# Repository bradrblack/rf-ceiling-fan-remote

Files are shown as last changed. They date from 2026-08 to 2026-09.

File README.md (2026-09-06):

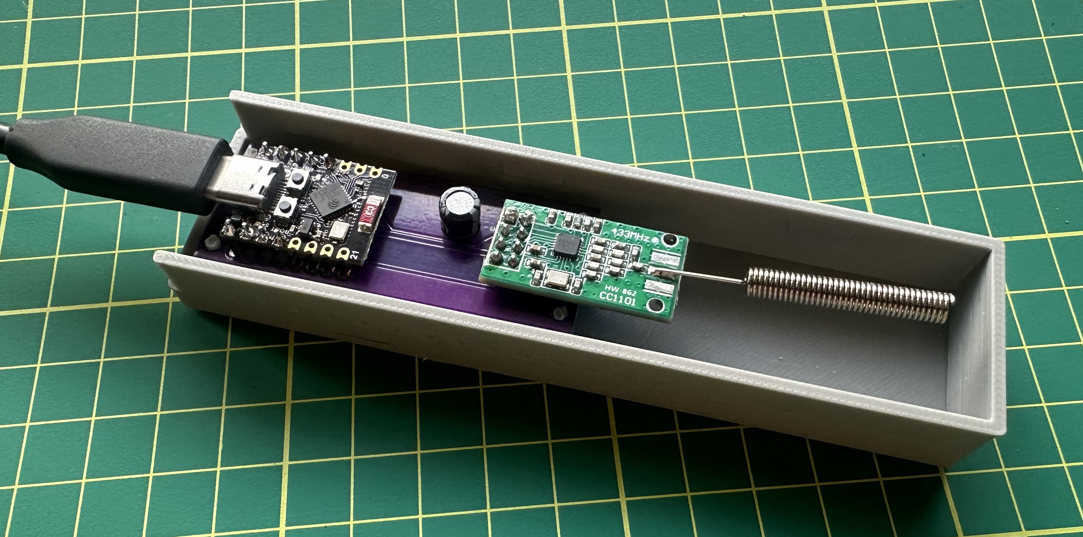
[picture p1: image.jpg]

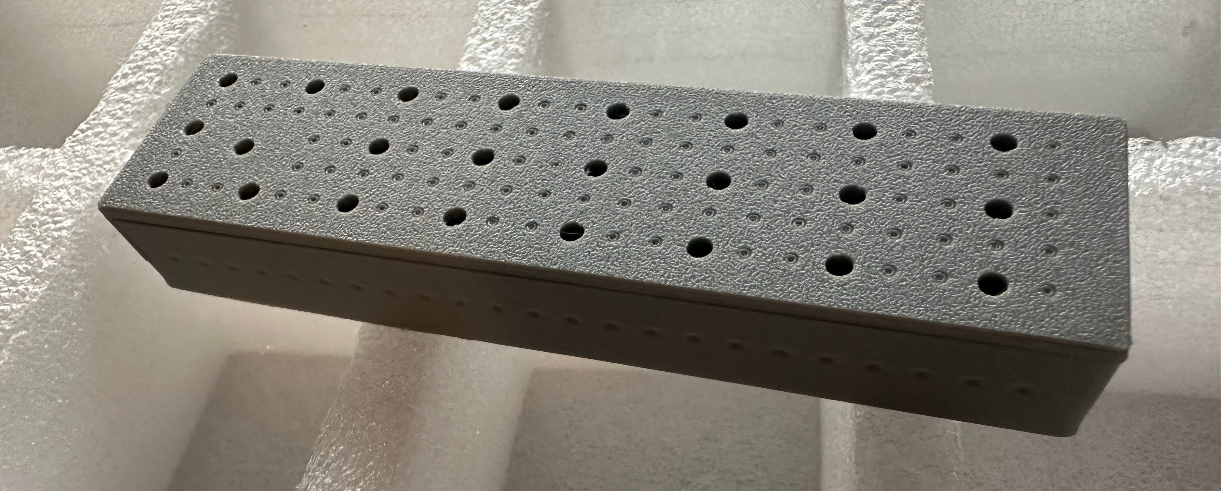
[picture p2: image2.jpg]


# rf-ceiling-fan-remote

Voice control for a combo ceiling fan + light, driven by directly cloning the RF remote's signal instead of physically pressing its buttons.

## Background

The original version of this project used a relay module wired across the buttons on the fan's remote control, triggered by an ESP32 listening on an Adafruit IO feed (fed via IFTTT/Google Assistant or iOS Shortcuts). It worked, but relays clicking against physical remote buttons is mechanically unreliable, and Google later removed the IFTTT conversational-actions feature that made flexible voice phrases possible.

This version replaces the relay entirely: a CC1101 RF transceiver connected directly to the ESP32 sniffs the remote's actual RF codes once, and then re-transmits them on command. Voice control goes through [SinricPro](https://sinric.pro), which exposes the fan and light as native devices in Google Home/Assistant (no relay, no fixed IFTTT phrases, natural voice commands like "set the fan to medium").

## Hardware

- ESP32-C3 Super Mini
- CC1101 RF transceiver module (433MHz-marketed hardware; this fan's remote actually operates at 304.25MHz, which the CC1101's synthesizer can still tune to directly)
- The fan's original remote control (used once, to sniff its codes)

## Wiring

| CC1101 pin | ESP32-C3 Super Mini pin |
|---|---|
| VCC | 3V3 (**3.3V only** — do not connect to 5V) |
| GND | GND |
| SCK | GPIO4 |
| MOSI | GPIO6 |
| MISO | GPIO5 |
| CS / SS | GPIO7 |
| GDO0 | GPIO3 |

A 100µF capacitor across the CC1101's VCC/GND pins (as close to the module as possible) was needed to get reliable SPI communication once the module started drawing the higher current TX requires — worth including if you build this yourself.

## Project structure

This is a multi-sketch PlatformIO project — each `.ino`/`.cpp` lives in its own subdirectory under `src/`, with a matching `[env]` in `platformio.ini` that filters the build to just that sketch:

| Environment | Source | Purpose |
|---|---|---|
| `c3_mini` (default) | `src/sniff.ino` | Listens on the CC1101 and prints the decimal code, bit length, protocol number, and pulse length for every button pressed on the physical remote. Run this first to capture your own remote's codes. |
| `c3_mini_tx` | `src/tx_test/` | Standalone transmit test — sends a single code on a timer, used for bench-testing range and signal timing independent of SinricPro/WiFi. |
| `c3_mini_fan` | `src/fan_control/` | The production firmware: connects to WiFi and SinricPro, and re-transmits the correct RF code when a fan or light command comes in. Also supports an optional second fan, independently TR313A or SST12 — see [Fan 2](#fan-2-experimental-second-fanremote) below (**experimental for SST12**). |
| `c3_mini_fan_public` | `src/fan_control_public/` | Same as `c3_mini_fan`, but for sharing with someone else who has the same fan/remote hardware — see [For other users](#for-other-users) below. **TR313A only — no fan2/SST12 support.** |

Build/upload a specific environment with:
```
pio run -e c3_mini_fan -t upload
```

## This fan's captured RF codes

Captured with `sniff.ino` — protocol 11, 12-bit, ~412µs pulse length.

This remote's codes encode two things in the same 12-bit value: which button was pressed, and the remote's 4-position **DIP switch** address (under the battery cover) — so a fan only responds to a remote configured with the same switch positions, and multiple fans can share the same frequency/protocol without answering each other's remote. Sniffing the same 5 buttons across 3 different switch combinations showed the low 4 bits are exactly the DIP address (switch 1 → bit 3 down to switch 4 → bit 0, **OFF = 1, ON = 0**) and the upper 8 bits are the button, unaffected by the switches:

| Button | Base code (all switches ON) |
|---|---|
| Fan low | 2032 |
| Fan medium | 3824 |
| Fan high | 3952 |
| Fan off | 4016 |
| Light toggle | 3056 |

A fan's actual codes are `base | address_nibble`. This fan's remote is set to 1=off, 2=off, 3=on, 4=on (address nibble `1100` = 12), giving 2044/3836/3964/4028/3068 — the codes this project originally shipped with, before the DIP addressing was understood.

The firmware computes the real codes at boot from the base table above plus the configured switch positions (`DIP_SWITCH_1..4` in `secrets.h`, or the portal fields for `c3_mini_fan_public`) — you don't need to sniff a separate code set per fan, just tell it the switch positions.

If you're cloning this for a different remote, re-run `sniff.ino` with all DIP switches ON to capture a fresh base table, and update `RF_CODE_*_BASE`/protocol/pulse length in `src/fan_control/fan_control.cpp` (and `fan_control_public.cpp`).

## Setup

1. **Sniff your remote's codes** — flash `c3_mini`, open a serial monitor, and press each button once. Note the decimal code, protocol number, and pulse length for each.
2. **Create a SinricPro account** at [sinric.pro](https://sinric.pro) and add two devices:
   - A **Fan (US)** device — supports the 3-speed range this fan uses
   - A **Switch** device — for the light toggle
   (Free tier allows up to 3 devices.)
3. **Fill in credentials** — copy `src/fan_control/secrets.h.example` to `src/fan_control/secrets.h` (gitignored) and fill in your WiFi SSID/password, SinricPro App Key/Secret, both device IDs, and your remote's DIP switch positions (`DIP_SWITCH_1..4` — see [This fan's captured RF codes](#this-fans-captured-rf-codes) above).
4. **Flash the production firmware**: `pio run -e c3_mini_fan -t upload`
5. **Link SinricPro to Google Home** from the Google Home app (Works with Google / SinricPro integration) — the fan and light will show up as native devices, controllable by voice with no fixed phrase list.

## For other users

`c3_mini_fan` (above) compiles your WiFi and SinricPro credentials in from `secrets.h`, which is convenient for one device you control but means sharing it with someone else requires them to edit and rebuild the source. `c3_mini_fan_public` (`src/fan_control_public/`) covers the fan 1 (TR313A) side of that same firmware — same CC1101 wiring, same RF codes/watchdogs/reliability behavior — but collects WiFi and SinricPro credentials at first boot through a [WiFiManager](https://github.com/tzapu/WiFiManager) captive portal instead, so someone with the **same fan/remote hardware** can flash it and configure it themselves without touching any code. It does not include `c3_mini_fan`'s [fan 2 support](#fan-2-experimental-second-fanremote) — that stays a `secrets.h`/rebuild-only, experimental feature for now.

This replaces the WiFi/SinricPro *credentials* and the remote's *DIP switch address* with portal fields — the base RF codes, CC1101 pins, and RF frequency/protocol are still compile-time constants in the source, since those are specific to this exact fan/remote model. It's for sharing the same physical build (same remote model, possibly a different individual fan/DIP address), not a general-purpose RF-cloning tool.

Setup, for the person flashing it:

1. **Flash it**: `pio run -e c3_mini_fan_public -t upload` (no `secrets.h` needed for this target).
2. **Connect to the setup network** — on first boot (or whenever it can't connect to a previously saved WiFi network), it opens a WiFi access point named `FanControllerSetup`. Connect to it from a phone or laptop.
3. **Fill in the portal** — a captive portal page should open automatically (or navigate to `192.168.4.1`); choose your home WiFi network and enter its password, plus your own SinricPro App Key, App Secret, Fan device ID, and Light device ID (from your own SinricPro account — see [Setup](#setup) above for creating those devices), your remote's 4 DIP switch positions (`on`/`off` each, matching the physical sliders under the battery cover), and optionally a device hostname (defaults to `myfan`, see below).
4. Submit — the device saves those to flash, computes its RF codes from the DIP positions, connects to your WiFi, and starts talking to SinricPro. If it ever fails to connect (e.g. moved to a new network), it automatically reopens the `FanControllerSetup` portal (DIP/SinricPro fields stay saved).

Unlike `c3_mini_fan`, this build has no ntfy.sh push notifications — reboot reasons are still logged to serial for anyone debugging, just not pushed anywhere, to keep the shared build simpler and dependency-free for other users.

### Hostname, mDNS, and OTA updates

The device is reachable on the local network at `http://<hostname>.local` (default hostname `myfan`, changeable in the setup portal). This is used for:

- **OTA flashing during development**: `pio run -e c3_mini_fan_public -t upload --upload-port myfan.local` flashes over WiFi instead of USB.
- **Firmware updates without a cable, for anyone**: hold the **BOOT button** (GPIO9 on most ESP32-C3 boards) for 10 seconds to wipe the saved WiFi/SinricPro config and reboot into the `FanControllerSetup` portal — then, instead of (or in addition to) reconfiguring WiFi, use the portal's built-in **Update** page to upload a `.bin` firmware file directly from a browser. This is a stock WiFiManager feature, not custom code. Note the setup AP is open/unauthenticated by default, so this window is only as secure as who can join your WiFi during the brief time it's active.

### Multiple fan units

The remote's DIP switches address multiple physically distinct fans on the same frequency/protocol — each fan only responds to a remote (or this controller) configured with its matching switch positions. If you have more than one of these controllers on the same network, give each a distinct hostname in the setup portal (`myfan`, `myfan2`, etc.) *and* set its own DIP fields to match the specific fan it's paired with.

## Fan 2 (experimental, second fan/remote)

`fan_control.cpp` can optionally drive a second physical fan alongside the first, each independently choosing its remote family via `FAN1_REMOTE_TYPE`/`FAN2_REMOTE_TYPE` in `secrets.h`:

- **`REMOTE_TR313A`** (fan 1's default) — same DIP-switch-addressed code family described above, just a different DIP address for the second fan.
- **`REMOTE_SST12`** (fan 2's default) — a different remote chip (used by some NOMA fans) that pairs directly to the fan's receiver instead of using DIP switches. It has no combined low/medium/high scheme — a dedicated button per speed (1-6) plus separate Off and Light-toggle buttons — and every button's code is unique to that one paired remote/receiver, with no derivable address formula the way TR313A has.

**This only works today if you already own a remote that's paired to the fan** — you sniff its buttons with `sniff.ino` (see `secrets.h.example` for the exact `FANn_RF_CODE_*` fields) and this firmware then impersonates that already-paired remote. There is no support for *pairing a new remote from scratch* (provisioning a bare receiver that has no working remote) — SST12 pairing is receiver-side (a power-cycle-then-button-combo handshake within a few seconds), and reproducing it would require reverse-engineering what a genuine remote actually transmits during that handshake, which hasn't been done. If you don't already have a paired, working remote for the fan you want to add, this won't help you.

Fan 2's fan and light SinricPro devices (`FAN2_ID`/`LIGHT2_ID`) are each independently optional, so a build can be fan-only, light-only, both, or neither, to fit within SinricPro's free 3-device tier or not.

Given the pairing gap above, this is closer to "works for one specific home's specific hardware" than a general-purpose feature — there's no `c3_mini_fan_public`-equivalent shareable build for fan 2 yet.

## Known limitation

The remote only has a single **light toggle** button, not separate on/off codes. The firmware tracks an assumed light state locally and only fires the toggle when a voice command's requested state differs from that tracked state. If the light is ever toggled some other way (the original remote, a wall switch), the tracked state can drift out of sync with reality — there's no feedback path from the fan to detect this.

## Reliability

The production firmware (`fan_control.cpp`) includes a few self-healing measures for a device meant to run unattended indefinitely:

- **Bounded WiFi connect at boot** — if WiFi doesn't connect within 30s, it reboots and retries, instead of hanging forever.
- **WiFi watchdog** — if WiFi drops and stays disconnected for 60s during normal operation, it reboots.
- **SinricPro watchdog** — WiFi staying connected doesn't guarantee SinricPro's WebSocket/TLS connection is actually up. Tracks time since the last successful SinricPro connection independently of WiFi state, and reboots if it's been unreachable for 10 minutes — added after a field log showed WiFi stay associated for over an hour while SinricPro was unreachable (DNS/TLS failures), invisible to the WiFi watchdog, recovering only because SinricPro's own internal retry logic eventually got lucky.
- **Radio watchdog** — every 60s, re-checks that the CC1101 still answers over SPI (the same VERSION-register check done at boot). Catches the radio silently wedging mid-operation — a failure mode where WiFi/SinricPro stay connected (Google Assistant still gives its ack "beep") but the RF commands stop actually transmitting. Fixes itself with a reboot rather than needing a manual power cycle.
- **Daily scheduled reboot** — once a day at 3am (`REBOOT_HOUR`, US Eastern via the `TZ_STRING` POSIX timezone string, DST-aware), it reboots proactively to guard against slow heap fragmentation from the long-running SinricPro WebSocket/TLS connection. Time is synced via NTP at boot.
- **Unexpected reset detection** — a crash, a hung SSL/network stack triggering the hardware watchdog, a brownout, etc. bypass the above watchdogs entirely, since they reset the chip before any of our own code gets to run. On the next boot, `esp_reset_reason()` is checked against the reset that just happened; if it wasn't a normal power cycle/reset button press or one of our own deliberate `ESP.restart()` calls, it's reported the same way the other reboots are, instead of leaving an unexplained gap.

If you're deploying this outside US Eastern, update `TZ_STRING` in `fan_control.cpp` to your own [POSIX TZ string](https://developer.ibm.com/articles/au-aix-posix/).

### Reboot notifications

Since these self-healing reboots would otherwise happen silently, the reason for each one is written to flash (NVS) right before restarting, then read back and pushed as a [ntfy.sh](https://ntfy.sh) notification once WiFi reconnects on the next boot — so a device that's rebooting every 10 minutes shows up as a stream of pushes on your phone instead of going unnoticed. A normal manual power cycle leaves no reason behind, so it stays quiet.

To enable it: pick a random, unguessable topic name (ntfy topics are unauthenticated — anyone who knows the exact name can read the notifications), set it as `NTFY_TOPIC` in `secrets.h`, and subscribe to that same topic in the [ntfy app](https://ntfy.sh/app) (iOS/Android) or web app.

### Acknowledgements

Thanks to Chris Butler for 3D printing the first case prototype!

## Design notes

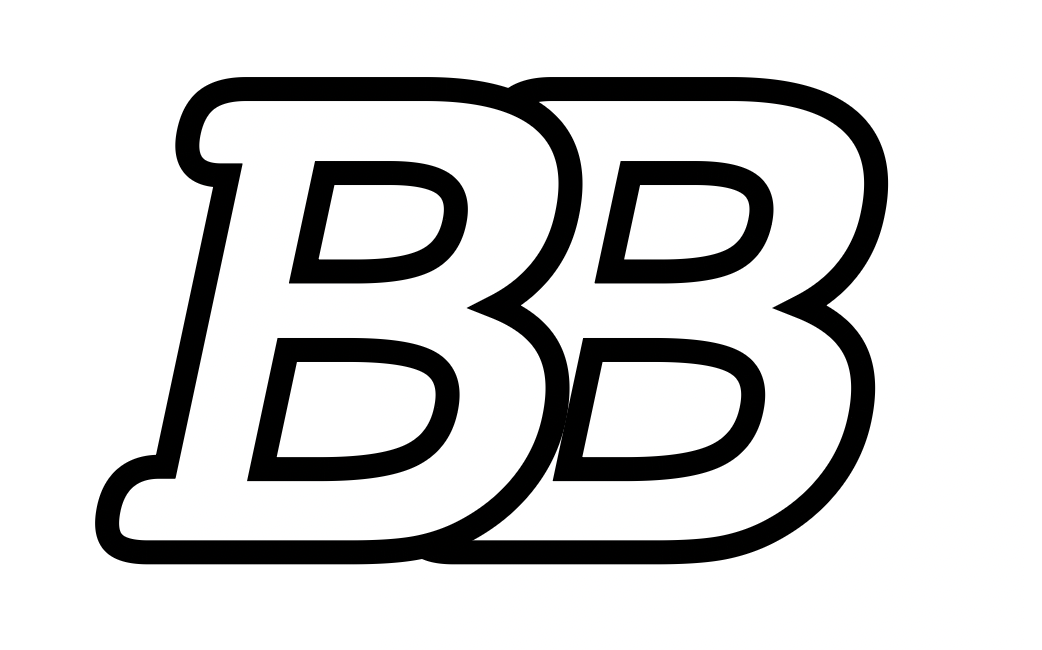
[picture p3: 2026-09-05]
hw/bb.png

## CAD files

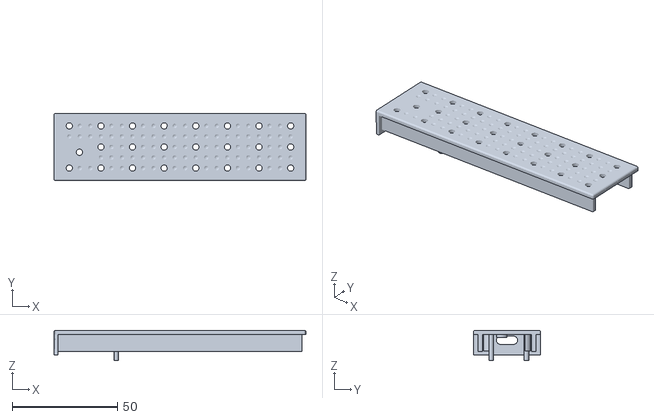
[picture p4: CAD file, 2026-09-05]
hw/case/top-final2.stl
119.5 x 32.0 x 14.3

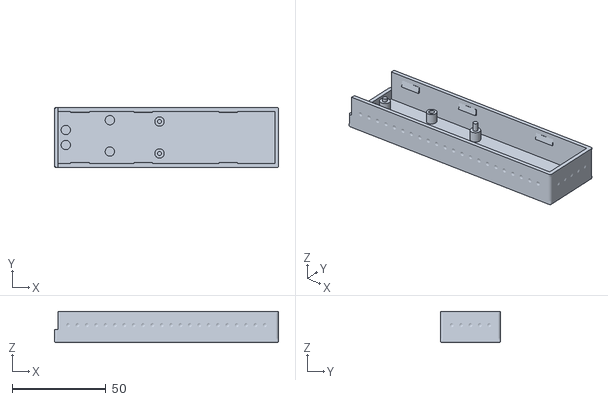
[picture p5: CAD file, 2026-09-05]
hw/case/bottom-final2.stl
119.5 x 32.0 x 16.6

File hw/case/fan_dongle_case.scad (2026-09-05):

// ESP32-C3 + CC1101 dongle case
// Companion to hw/esp32c3_cc1101_dongle.kicad_pcb
//
// Board/hole dimensions below are read directly from
// hw/esp32c3_cc1101_dongle.kicad_pcb (MEASURED). Component heights, the
// reset-button tunnel position, and the LED/cable dimensions are
// ESTIMATES based on typical ESP32-C3 Super Mini layout -- verify against
// your actual modules before printing, especially the near_holes'
// position and the pin/hook dimensions (test-fit before committing).
//
// v1.2 (see hw-v1.1 tag for the prior geometry): the board's near/USB
// edge was trimmed back flush with the ESP32 module's own edge, so the
// module's onboard USB-C connector -- which already overhung its own
// sub-board by ~1mm -- now overhangs the CARRIER board's edge too. The
// leading wall's port opening shrank to match: it's sized to the bare
// connector now, not a cable plug's shell, and the board sits close
// enough to that wall (near_end_clearance, not the full board_margin)
// that the connector ends up embedded in the wall's own thickness rather
// than clear of it. Six mounting holes now split into three roles
// (far_holes, middle_holes, near_holes -- see their own comments up top)
// instead of one uniform set of four.
//
// Assembly changed along with that: a tight port opening around an
// embedded connector can't be dropped straight down over an
// already-seated board (the leading wall's own solid material would
// sweep through the connector's height on the way down -- there's no
// direction to lower a fully rigid shell from that clears it). Order is
// now: lay the TOP piece down (ceiling on the table, everything else
// pointing up), place the bare board onto it and push the USB-C
// connector into the tight port opening (a small, mostly horizontal
// motion, not a drop), then lower the whole top+board unit as one piece
// straight down onto the tray's pins. The middle_holes' pin (hanging
// from the ceiling instead of standing up from the tray, unlike
// far_holes/near_holes) is what gives the board real registration in
// that middle step, instead of relying on nothing but the connector's
// friction fit while the rest of the board is held by hand. See
// middle_holes'/near_holes' own comments up top for how each of the
// three hole roles is actually built.
//
// No screws hold the PCB itself. Alignment pins poke through the board's
// mounting holes -- the tray hosts them at far_holes/near_holes, the
// ceiling hosts them at middle_holes. Wherever a pin lives on the tray, a
// plain washer-shaped hook post hangs from the ceiling over it, clearing
// it on the way down and coming to rest just above the board once
// seated; it holds the PCB down passively, the same way a washer under a
// screw head does, simply because the rigid top above it isn't going
// anywhere. That "isn't going anywhere" is doing real work: unlike a
// slide-to-lock mechanism, a snug friction fit alone does not resist
// being pulled straight back up, and a slotted/keyed hook can't either
// without either colliding with the pin during any sideways lock motion
// or requiring a wider-headed pin than this design uses (the geometry
// was checked both ways). What actually keeps the case shut is a
// snap-fit latch: two
// flexible cantilever tabs per long wall (four total, spread toward each
// end rather than one centered pair, so both ends of the ceiling panel
// get held down instead of just the middle), each engaging a ramped catch
// ridge on the tray wall as the top drops down -- ramped on its entry
// side for a smooth push going in, flat on its catch side so pulling the
// top back off means deliberately flexing the tab, not just reversing
// the same smooth path (a locking screw was tried first, but the
// CC1101's antenna coils well past the board's far edge, right where the
// screw boss needed to sit). An earlier version of this also tried
// adding a raised nub to each tab as a second, more visible catch
// feature; it's gone now -- on one wall it collided with the tray's own
// solid material (not flexible, so nothing could actually get past it),
// and on the other it pointed away from the ridge and did nothing, so it
// wasn't adding a real second catch either way. The catch ridge and the
// tab's own thinned, flexible section are the visible features on the
// tray and the lid respectively (see skirt_wall(), snap_ridge_low/high).
// Everything else here is fit
// and alignment, not a lock. The tray's open (cable) end has a short
// fixed stub wall covering its bottom third; the top's leading wall picks
// up right where that stops and covers the rest, closing off the whole
// opening between them except for the tight, flush USB-C port opening. Since
// the top's leading wall spans the tray's full width (Y=0 to outer_h) and
// the tray's own long walls run its full length (X=0 to outer_w), their
// footprints would otherwise overlap in a solid block at each of the two
// near corners, above the stub wall's height -- two separate parts
// trying to occupy the same physical space, which would make it
// physically impossible for the top to ever seat on the tray. The tray's
// long walls are notched clear of that block at each near corner so the
// leading wall actually has
// somewhere to drop into (see the notch cut in bottom_tray()).
// The ceiling and all 3 closed tray walls (both long walls and the far
// wall -- everywhere except the floor) carry a plain dimple-grid surface
// texture (see dot_field()) -- a fully deterministic grid of shallow
// round dimples, no randomness, reused on every surface via a simple
// translate/rotate rather than one-off geometry per side. On the
// ceiling, every other grid column is a real through-hole instead of a
// dimple, which is what actually vents the case and lets the onboard LED
// show through.
// Exterior edges carry a cosmetic rounded fillet (not a chamfer): the
// ceiling's top edge and corners, and the tray floor's bottom edge and
// corners -- the two outermost surfaces of the assembled case, each
// exposed on its own with nothing else to align to. The tray walls'
// TOP edges are deliberately left plain/square, unlike those two: the
// top piece's ceiling sits flush on top of the walls at their full,
// unrounded footprint, so a wall-edge bevel there would recede inward
// right where the ceiling's flush edge continues straight up outside of
// it, leaving a visible groove at the seam instead of one flat face.
// The vertical corners round off independently of that -- all 4 (see
// corner_round_cut_full()), tapering from a fat corner_fillet radius in
// the middle back down to match whatever's at each end: the floor's own
// dome at the bottom everywhere, and at the top either back to square
// (the far end, matching the plain wall top edge and the ceiling's own
// square underside above it) or straight up at full radius into the
// top's leading wall, which continues the taper down to square itself
// (the near/USB end, where the top's leading wall -- not the tray's
// short stub wall -- is what's actually exposed for most of the height).
//
// Render in OpenSCAD, or from the command line:
//   openscad -o tray.stl   -D 'part="tray"' fan_dongle_case.scad
//   openscad -o top.stl    -D 'part="top"'  fan_dongle_case.scad
//   openscad -o preview.png -D 'part="both"' --imgsize=1200,900 --camera=34,12,10,55,0,25,220 fan_dongle_case.scad
//   openscad -o fit.png     -D 'part="fit"'  --imgsize=1200,900 --camera=34,12,10,55,0,25,220 fan_dongle_case.scad
//     ("fit" = tray + a translucent PCB/module reference, no top -- for checking fit; not a real part)
//   openscad -o snap_detail.png -D 'part="detail"' --imgsize=1200,900 --camera=34,12,10,55,0,25,220 fan_dongle_case.scad
//     ("detail" = tray+top assembled, tray rendered translucent so the catch ridges show through
//      the wall right where the top's tabs sit; not a printable part)

// ==========================================
// MEASURED -- from hw/esp32c3_cc1101_dongle.kicad_pcb, local origin at
// board bottom-left corner
// ==========================================
// v1.2: the board's own near/USB edge was trimmed back to align with the
// ESP32 module's edge (kicad Edge.Cuts moved from X=50 to X=53.75), so the
// module's onboard USB-C connector -- which already overhung its OWN
// sub-board by ~1mm -- now overhangs the CARRIER board's edge too, instead
// of sitting inset behind it. Local X=0 is that new trimmed edge. board_w
// shrank to match (was 60, spanning kicad X 50-110).
board_w = 56.25;         // board X (kicad Edge.Cuts: 53.75-110)
board_h = 24;             // board Y (kicad Edge.Cuts: 38-62)
board_t = 1.6;             // standard PCB thickness
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

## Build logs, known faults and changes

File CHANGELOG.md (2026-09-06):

# Changelog

Notable changes to this project, grouped by theme rather than by individual commit. Dates are when the work landed on `main`; the two production firmware builds (`c3_mini_fan`, `c3_mini_fan_public`) each carry their own `FIRMWARE_VERSION` string (`YYYY-MM-DDrN`) bumped on every flash-worthy change, which you can cross-reference against a device's boot log.

## Unreleased

### Added
- **Fan 2 support in `c3_mini_fan`** — a second, independently-configured fan alongside the original fan+light. Each of fan 1 and fan 2 picks its remote family via `FAN1_REMOTE_TYPE`/`FAN2_REMOTE_TYPE` in `secrets.h`: `REMOTE_TR313A` (the original DIP-switch-addressed family) or `REMOTE_SST12` (a NOMA remote with a dedicated button per speed 1-6, no DIP addressing). Any combination is supported; existing `secrets.h` files keep working unchanged since fan 1 still defaults to TR313A. Fan 2's fan and light SinricPro devices (`FAN2_ID`/`LIGHT2_ID`) are each independently optional.
  - **Experimental for SST12**: only works by impersonating a remote already paired to the fan (sniff its buttons with `sniff.ino`, replay them). Pairing a brand-new remote from scratch against a bare receiver is unsolved. See the README's [Fan 2](README.md#fan-2-experimental-second-fanremote) section.
  - **Not included in `c3_mini_fan_public`** — the shareable/WiFiManager build stays TR313A-only for now.
- **`sniff.ino` raw pulse-timing mode** (`RAW_MODE`, default off) — bypasses rc-switch's built-in protocol matching entirely and dumps raw GDO0 pulse timings, for diagnosing a button that produces no decoded output (tells apart "nothing arriving" from "arriving but not matching a known protocol").
- **`sniff.ino` configurable frequency** (`SNIFF_MHZ`) — previously hardcoded to 304.25MHz; now a single constant to change before reflashing to try a different candidate frequency.

### Fixed
- **Radio left stuck out of TX mode after a frequency change.** `sendFan1Code()`/`sendFan2Code()` were calling the CC1101 driver's `setMHZ()` alone, which only rewrites the frequency registers without re-strobing the chip back into TX state (the driver's `SetTx(float)` does `SIDLE → setMHZ() → STX` as one atomic sequence — `setMHZ()` alone does not). This silently broke fan 1's previously-working transmission once fan 2 sends started retuning the radio out from under it. Centralized into `tuneRadioForFan1()`/`tuneRadioForFan2()`, called before every send (including light toggles), so this can't drift out of sync again.
- Fan 2 RF code storage was `uint16_t`, which would have silently truncated SST12's ~434-million-value codes. Switched to `uint32_t`.

## 2026-08-26 – 2026-08-30 — Custom PCB and 3D-printed case
- Parametric OpenSCAD case design for the ESP32-C3 + CC1101 dongle, iterated through several revisions (snap-fit assembly, button/vent placement, USB cutout, real component dimensions).
- Custom KiCad PCB: socketed ESP32-C3 SuperMini + CC1101 module carrier board.

## 2026-08-22 – 2026-08-25 — Shareable public build
- Added `c3_mini_fan_public` (`src/fan_control_public/`): same RF/reliability behavior as the production firmware, but collects WiFi and SinricPro credentials — plus the remote's DIP switch address — through a WiFiManager captive portal at first boot, so someone with the same fan/remote hardware can flash and configure it themselves with no code changes.
- Hostname/mDNS, ArduinoOTA (WiFi flashing), and a BOOT-button-hold factory reset for the public build.
- Made the public build tolerant of a missing/disconnected CC1101 module (reports the failure instead of hanging).

## 2026-08-10 – 2026-08-22 — Reliability hardening
- WiFi watchdog (reboot if disconnected too long) and a daily scheduled reboot to guard against slow heap fragmentation.
- SinricPro connectivity watchdog, independent of `WiFi.status()` (catches the case where WiFi stays associated but SinricPro itself is unreachable).
- Radio watchdog — periodically re-checks the CC1101 is still answering over SPI, catching the radio silently wedging mid-operation.
- Reboot reason persisted to flash and pushed via [ntfy.sh](https://ntfy.sh) on the next boot, so self-healing reboots are visible instead of silent.
- Detection for resets that bypass the app's own watchdogs entirely (crash/panic, brownout, task/interrupt watchdog).
- Timestamped log output once NTP has synced; background clock-jump detection.

## 2026-08-27 — DIP-switch addressing discovered
- Sniffing the same buttons across multiple DIP switch combinations revealed the remote encodes its 4-position DIP address as the low 4 bits of each 12-bit code. The firmware now computes a fan's actual codes at boot from a shared base table plus the configured switch positions, instead of needing a full separate code set sniffed per fan.

## 2026-08-09 — RF replay replaces the relay-based original
- Replaced the original relay-across-the-remote-buttons approach with a CC1101 RF transceiver that sniffs the remote's real RF codes once and re-transmits them directly. Voice control moved from IFTTT/Adafruit IO (discontinued) to [SinricPro](https://sinric.pro), exposing the fan and light as native Google Home/Assistant devices.

## 2024-07-06 — Original relay-based version
- Initial project: a relay module wired across the physical remote's buttons, triggered by an ESP32 listening on an Adafruit IO feed fed via IFTTT/Google Assistant or iOS Shortcuts.

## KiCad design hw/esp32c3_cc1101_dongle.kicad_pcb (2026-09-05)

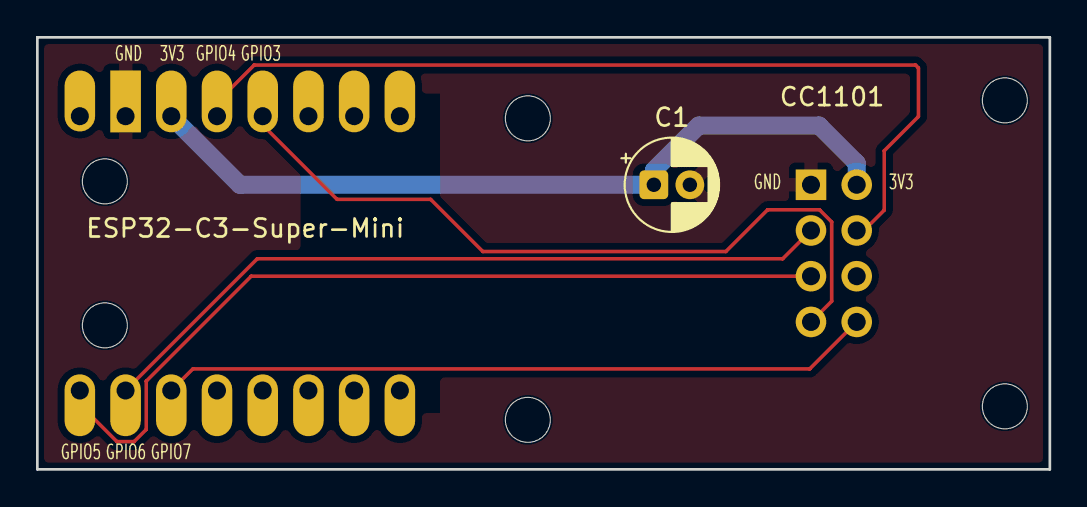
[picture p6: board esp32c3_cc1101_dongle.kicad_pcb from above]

Board: 2 copper layers, 56.2 x 24.0 mm, 3 parts (0 on the bottom side), 7 nets.

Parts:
C1: 100uF; CP_Radial_D5.0mm_P2.00mm
CC1101: CC1101_Module; CC1101_2x4_Socket
ESP32-C3-Super-Mini: ESP32-C3_SuperMini; ESP32-C3_SuperMini_FaceUp

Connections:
3V3: C1.1, CC1101.5, ESP32-C3-Super-Mini.3
CC1101_GDO0: CC1101.4, ESP32-C3-Super-Mini.5
GND: C1.2, CC1101.1, ESP32-C3-Super-Mini.2
SPI_CSN: CC1101.8, ESP32-C3-Super-Mini.11
SPI_MISO: CC1101.3, ESP32-C3-Super-Mini.9
SPI_MOSI: CC1101.2, ESP32-C3-Super-Mini.10
SPI_SCK: CC1101.6, ESP32-C3-Super-Mini.4

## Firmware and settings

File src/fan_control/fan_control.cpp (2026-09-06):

#include <Arduino.h>
#include <WiFi.h>
#include <WiFiClientSecure.h>
#include <HTTPClient.h>
#include <Preferences.h>
#include <time.h>
#include <cstdarg>
#include <cstring>
#include <cstdlib>
#include <esp_system.h>
#include <esp_wifi.h>
#include <esp32c3/rom/rtc.h>
#include <ELECHOUSE_CC1101_SRC_DRV.h>
#include <RCSwitch.h>
#include "SinricPro.h"
#include "SinricProFanUS.h"
#include "SinricProSwitch.h"

// Remote family identifiers for FAN2_REMOTE_TYPE (chosen in secrets.h),
// defined before that include so the choice reads normally top-to-bottom.
#define REMOTE_TR313A 1
#define REMOTE_SST12  2

#include "secrets.h"

// Bump this on each flash you want to be able to identify later (e.g. to
// confirm an OTA update actually took) -- format: YYYY-MM-DDrN.
#define FIRMWARE_VERSION "2026-09-05r4"

const char *BANNER =
R"(  __  __         _____
 |  \/  |_   _  |  ___|_ _ _ __
 | |\/| | | | | | |_ / _` | '_ \
 | |  | | |_| | |  _| (_| | | | |
 |_|  |_|\__, | |_|  \__,_|_| |_|
         |___/                  )";

// ==========================================
// CC1101 wiring (ESP32-C3 Super Mini) -- same as sniff.ino / tx_test.cpp
// ==========================================
#define C3_CC1101_CLK   4
#define C3_CC1101_MISO  5
#define C3_CC1101_MOSI  6
#define C3_CC1101_CS    7
#define C3_CC1101_GDO0  3

// Onboard blue LED on most ESP32-C3 Super Mini boards -- active-low (LOW =
// on). Blinks for LED_BLINK_MS every time an RF code is sent, as a visual
// "yes, it's actually transmitting" check. If your board's LED is on a
// different pin or wired active-high, adjust these two.
#define LED_PIN         8
#define LED_ON          LOW
#define LED_OFF         HIGH
#define LED_BLINK_MS    500

// TR313A family constants -- shared by any fan slot that selects
// REMOTE_TR313A. The remote's DIP switches select the address, not a
// different code family, so these values are the same regardless of
// which fan slot uses them.
#define RF_MHZ          304.25
#define RF_PROTOCOL     11
#define RF_PULSE_US     412
#define RF_BITLENGTH    12

// Base codes captured with sniff.ino, with all 4 DIP switches ON (address
// nibble 0000). This remote encodes its DIP switch address as the low 4
// bits of the 12-bit code, OFF=1/ON=0 per switch (switch 1 = bit 3 down to
// switch 4 = bit 0) -- confirmed by sniffing the same 5 buttons across 3
// different switch combinations and finding only that nibble changes.
// Re-run sniff.ino with all switches ON to recapture these for a different
// remote.
#define RF_CODE_FAN_LOW_BASE    2032
#define RF_CODE_FAN_MEDIUM_BASE 3824
#define RF_CODE_FAN_HIGH_BASE   3952
#define RF_CODE_FAN_OFF_BASE    4016
#define RF_CODE_LIGHT_BASE      3056

// SST12 family constants -- shared by any fan slot that selects
// REMOTE_SST12. Captured with sniff.ino at 433.92MHz against a real NOMA
// SST12 remote: frequency, rc-switch protocol number, pulse length, and
// bit length are properties of the SST12 chip itself (confirmed the same
// across that remote's Off/Light/Speed1-6 buttons), so they're shared
// here too -- only the actual per-button codes are unique per paired
// remote/receiver, supplied per-slot as FANn_RF_CODE_* in secrets.h.
#define SST12_RF_MHZ       433.92
#define SST12_RF_PROTOCOL  1
#define SST12_RF_PULSE_US  257
#define SST12_RF_BITLENGTH 32

// Address nibble encoded by a TR313A remote's DIP switches: each switch
// contributes one bit (1->bit3 .. 4->bit0), OFF = 1, ON = 0. OR'd with the
// base codes above to get that fan's actual RF codes.
uint8_t dipAddressNibble(bool sw1On, bool sw2On, bool sw3On, bool sw4On) {
  return (sw1On ? 0 : 8) | (sw2On ? 0 : 4) | (sw3On ? 0 : 2) | (sw4On ? 0 : 1);
}

// ==========================================
// Fan 1 and Fan 2 -- each independently picks its remote family
// ==========================================
// Every combination is supported: both TR313A, both SST12, or one of
// each. FAN1_REMOTE_TYPE defaults to REMOTE_TR313A (fan 1's original,
// still-deployed config) so existing secrets.h files keep working
// unchanged; FAN2_REMOTE_TYPE defaults to REMOTE_SST12.
#ifndef FAN1_REMOTE_TYPE
#define FAN1_REMOTE_TYPE REMOTE_TR313A
#endif
#ifndef FAN2_REMOTE_TYPE
#define FAN2_REMOTE_TYPE REMOTE_SST12
#endif

#if FAN1_REMOTE_TYPE == REMOTE_TR313A
#define FAN1_RF_MHZ       RF_MHZ
#define FAN1_RF_PROTOCOL  RF_PROTOCOL
#define FAN1_RF_PULSE_US  RF_PULSE_US
#define FAN1_RF_BITLENGTH RF_BITLENGTH
#define FAN1_MAX_SPEED    3
#elif FAN1_REMOTE_TYPE == REMOTE_SST12
#define FAN1_RF_MHZ       SST12_RF_MHZ
#define FAN1_RF_PROTOCOL  SST12_RF_PROTOCOL
#define FAN1_RF_PULSE_US  SST12_RF_PULSE_US
#define FAN1_RF_BITLENGTH SST12_RF_BITLENGTH
#define FAN1_MAX_SPEED    6
#else
#error "Unknown FAN1_REMOTE_TYPE -- must be REMOTE_TR313A or REMOTE_SST12"
#endif

#if FAN2_REMOTE_TYPE == REMOTE_TR313A
#define FAN2_RF_MHZ       RF_MHZ
#define FAN2_RF_PROTOCOL  RF_PROTOCOL
#define FAN2_RF_PULSE_US  RF_PULSE_US
#define FAN2_RF_BITLENGTH RF_BITLENGTH
#define FAN2_MAX_SPEED    3
#elif FAN2_REMOTE_TYPE == REMOTE_SST12
#define FAN2_RF_MHZ       SST12_RF_MHZ
#define FAN2_RF_PROTOCOL  SST12_RF_PROTOCOL
#define FAN2_RF_PULSE_US  SST12_RF_PULSE_US
#define FAN2_RF_BITLENGTH SST12_RF_BITLENGTH
#define FAN2_MAX_SPEED    6
#else
#error "Unknown FAN2_REMOTE_TYPE -- must be REMOTE_TR313A or REMOTE_SST12"
#endif

// Fan 1 code storage. TR313A uses DIP_SWITCH_1..4 (unchanged name, for
// backward compatibility with existing secrets.h files); SST12 uses fixed
// per-unit codes from FAN1_RF_CODE_* in secrets.h.
uint32_t rfCodeFan1Off, rfCodeFan1Light;
#if FAN1_REMOTE_TYPE == REMOTE_TR313A
uint32_t rfCodeFan1Low, rfCodeFan1Medium, rfCodeFan1High;
#else
uint32_t rfCodeFan1Speed[FAN1_MAX_SPEED]; // index 0..5 = speed 1..6
#endif

void computeRfCodesFan1() {
#if FAN1_REMOTE_TYPE == REMOTE_TR313A
  uint8_t addr1 = dipAddressNibble(DIP_SWITCH_1, DIP_SWITCH_2, DIP_SWITCH_3, DIP_SWITCH_4);
  rfCodeFan1Low    = RF_CODE_FAN_LOW_BASE    | addr1;
  rfCodeFan1Medium = RF_CODE_FAN_MEDIUM_BASE | addr1;
  rfCodeFan1High   = RF_CODE_FAN_HIGH_BASE   | addr1;
  rfCodeFan1Off    = RF_CODE_FAN_OFF_BASE    | addr1;
  rfCodeFan1Light  = RF_CODE_LIGHT_BASE      | addr1;
#else // REMOTE_SST12 -- fixed codes, no DIP address
  rfCodeFan1Off      = FAN1_RF_CODE_OFF;
  rfCodeFan1Light    = FAN1_RF_CODE_LIGHT;
  rfCodeFan1Speed[0] = FAN1_RF_CODE_SPEED1;
  rfCodeFan1Speed[1] = FAN1_RF_CODE_SPEED2;
  rfCodeFan1Speed[2] = FAN1_RF_CODE_SPEED3;
  rfCodeFan1Speed[3] = FAN1_RF_CODE_SPEED4;
  rfCodeFan1Speed[4] = FAN1_RF_CODE_SPEED5;
  rfCodeFan1Speed[5] = FAN1_RF_CODE_SPEED6;
#endif
}

// Fan 2 code storage -- same shape as fan 1's above.
uint32_t rfCodeFan2Off;
uint32_t rfCodeFan2Light; // only meaningful/sent if LIGHT2_ID is defined
#if FAN2_REMOTE_TYPE == REMOTE_TR313A
uint32_t rfCodeFan2Low, rfCodeFan2Medium, rfCodeFan2High;
#else
uint32_t rfCodeFan2Speed[FAN2_MAX_SPEED]; // index 0..5 = speed 1..6
#endif

void computeRfCodesFan2() {
#if FAN2_REMOTE_TYPE == REMOTE_TR313A
  uint8_t addr2 = dipAddressNibble(FAN2_DIP_SWITCH_1, FAN2_DIP_SWITCH_2,
                                    FAN2_DIP_SWITCH_3, FAN2_DIP_SWITCH_4);
  rfCodeFan2Low    = RF_CODE_FAN_LOW_BASE    | addr2;
  rfCodeFan2Medium = RF_CODE_FAN_MEDIUM_BASE | addr2;
  rfCodeFan2High   = RF_CODE_FAN_HIGH_BASE   | addr2;
  rfCodeFan2Off    = RF_CODE_FAN_OFF_BASE    | addr2;
  rfCodeFan2Light  = RF_CODE_LIGHT_BASE      | addr2;
#else // REMOTE_SST12 -- fixed codes, no DIP address
  rfCodeFan2Off      = FAN2_RF_CODE_OFF;
  rfCodeFan2Light    = FAN2_RF_CODE_LIGHT;
  rfCodeFan2Speed[0] = FAN2_RF_CODE_SPEED1;
  rfCodeFan2Speed[1] = FAN2_RF_CODE_SPEED2;
  rfCodeFan2Speed[2] = FAN2_RF_CODE_SPEED3;
  rfCodeFan2Speed[3] = FAN2_RF_CODE_SPEED4;
  rfCodeFan2Speed[4] = FAN2_RF_CODE_SPEED5;
  rfCodeFan2Speed[5] = FAN2_RF_CODE_SPEED6;
#endif
}

// ==========================================
// Reliability: WiFi watchdog + daily reboot
// ==========================================
// If WiFi can't (re)connect within this long, or stays disconnected this
// long during normal operation, reboot rather than sit there dead.
const unsigned long WIFI_CONNECT_TIMEOUT_MS = 30000;
const unsigned long WIFI_DOWN_REBOOT_MS     = 60000;
unsigned long wifiDownSince = 0;

// WiFi.status() staying connected doesn't mean SinricPro is reachable --
// seen in the field: WiFi stayed associated for over an hour while
// SinricPro itself was unreachable (DNS/TLS failures), with no watchdog
// catching it since that failure is invisible to WiFi.status(). Tracks
// time since the last successful SinricPro connection independently and
// reboots if it's been too long, regardless of WiFi state.
const unsigned long SINRIC_DOWN_REBOOT_MS = 600000; // 10 min
unsigned long sinricDownSince = 0;

// Periodically confirms the CC1101 is still answering over SPI (same
// VERSION-register check used at boot). Catches the radio silently wedging
// mid-operation -- SinricPro/WiFi stay up (Google still hears an ack "beep")
// but sendFan1Code()/sendFan2Code()/onLightPowerState() stop actually
// transmitting anything.
const unsigned long RADIO_CHECK_INTERVAL_MS = 60000;
unsigned long lastRadioCheck = 0;

// Detects the wall clock (time()) jumping relative to uptime (millis()).
// The SNTP client re-syncs periodically in the background, not just at
// boot -- if the RTC came up wrong after a hard reset, a later resync can
// silently snap the clock by minutes or hours, making every log timestamp
// since boot misleading with no visible indication it happened.
const unsigned long CLOCK_CHECK_INTERVAL_MS = 30000;
const long CLOCK_JUMP_THRESHOLD_SEC = 120; // ignore ordinary small NTP drift corrections
unsigned long lastClockCheckMillis = 0;
time_t lastClockCheckTime = 0;

// Scheduled reboot once a day, at a fixed local hour, to guard against slow
// heap fragmentation from a long-running WebSocket/TLS/JSON connection.
// POSIX TZ string (not a fixed UTC offset) so DST transitions are handled
// automatically -- US Eastern: EST=UTC-5, switches to EDT=UTC-4 on the
// 2nd Sunday of March and back on the 1st Sunday of November.
#define TZ_STRING        "EST5EDT,M3.2.0,M11.1.0/2"
#define REBOOT_HOUR      3
const char* NTP_SERVER = "pool.ntp.org";
int lastRebootDay = -1;

// The daily reboot is routine, not a symptom of a problem, so it's excluded
// from ntfy notifications by default -- only the exception reboots (WiFi
// timeout, WiFi watchdog, radio watchdog) are worth a push. Flip to true if
// you want every reboot reported.
#define NOTIFY_DAILY_REBOOT true
#define REASON_DAILY_REBOOT "Daily scheduled reboot"

// ==========================================
// Timestamped logging
// ==========================================
// Prefixes every log line with the synced wall-clock time (once NTP has
// synced) or uptime in seconds (before that / if sync ever fails), so log
// output can be correlated with real time instead of just relative order.
const char *logTimestamp() {
  static char buf[32];
  time_t now = time(nullptr);
  if (now > 100000) {
    struct tm timeinfo;
    localtime_r(&now, &timeinfo);
    strftime(buf, sizeof(buf), "%Y-%m-%d %H:%M:%S %Z", &timeinfo);
  } else {
    snprintf(buf, sizeof(buf), "+%lus", millis() / 1000);
  }
  return buf;
}

void logf(const char *fmt, ...) {
  char msg[192];
  va_list args;
  va_start(args, fmt);
  vsnprintf(msg, sizeof(msg), fmt, args);
  va_end(args);
  Serial.printf("[%s] %s\r\n", logTimestamp(), msg);
}

// ==========================================
// Reboot reporting (ntfy.sh)
// ==========================================
// The device otherwise self-heals silently -- to see *how often* that's
// happening (rather than just "it's fine again after a power cycle"), the
// reason for each self-triggered reboot is written to NVS flash right
// before restarting, then read back and pushed to ntfy.sh once WiFi is up
// on the next boot. A manual power cycle leaves no reason behind, so it
// stays quiet -- only self-triggered reboots notify.
Preferences prefs;

void recordRebootReason(const char *reason) {
  prefs.begin("fanctl", false);
  prefs.putString("last_reason", reason);
  // The daily reboot isn't a symptom of anything -- only count exception
  // reboots, so "reboot #N" actually signals something went wrong N times.
  if (strcmp(reason, REASON_DAILY_REBOOT) != 0) {
    prefs.putUInt("reboot_count", prefs.getUInt("reboot_count", 0) + 1);
  }
  prefs.end();
}

// Detects a reboot that bypassed our own recordRebootReason() calls entirely
// -- a crash, a hung SSL/network stack triggering the hardware watchdog,
// a brownout, etc. Those resets happen before our code gets a chance to run,
// so without this they're invisible: no log line, no ntfy notification, just
// a gap. Must run before anything else in setup() could call
// recordRebootReason() for this boot cycle (e.g. a WiFi connect timeout),
// since it decides based on whether a reason is already recorded.
void checkUnexpectedReset() {
  prefs.begin("fanctl", true);
  String reason = prefs.getString("last_reason", "");
  prefs.end();
  if (reason.length() > 0) return; // a deliberate reboot already recorded this

  esp_reset_reason_t r = esp_reset_reason();
  // POWERON/EXT are manual power cycles or the reset button -- stay quiet,
  // same as any other manual power cycle. SW is our own ESP.restart(),
  // which would already have recorded a reason if it came from our code.
  if (r == ESP_RST_POWERON || r == ESP_RST_EXT || r == ESP_RST_SW) return;

  // esp_reset_reason() doesn't classify a reset triggered by a serial tool
  // toggling RTS (esptool during flashing, or opening a monitor) on this
  // IDF version -- it falls through to ESP_RST_UNKNOWN alongside genuine
  // crashes. Check the raw hardware reset-reason code directly so flashing/
  // monitoring the device doesn't generate a false "unexpected reset" alert.
  RESET_REASON raw = rtc_get_reset_reason(0);
  if (raw == USB_UART_CHIP_RESET || raw == USB_JTAG_CHIP_RESET) return;

  const char *desc;
  switch (r) {
    case ESP_RST_PANIC:     desc = "crash/panic"; break;
    case ESP_RST_INT_WDT:   desc = "interrupt watchdog"; break;
    case ESP_RST_TASK_WDT:  desc = "task watchdog"; break;
    case ESP_RST_WDT:       desc = "other watchdog"; break;
    case ESP_RST_BROWNOUT:  desc = "brownout"; break;
    case ESP_RST_DEEPSLEEP: desc = "deep sleep wake"; break;
    case ESP_RST_SDIO:      desc = "SDIO"; break;
    default:                desc = "unknown"; break;
  }
  char buf[48];
  snprintf(buf, sizeof(buf), "Unexpected reset (%s)", desc);
  recordRebootReason(buf);
}

void sendNtfy(const String &title, const String &message) {
  if (WiFi.status() != WL_CONNECTED) return;
  logf("[ntfy] Sending: \"%s\" - \"%s\"", title.c_str(), message.c_str());
  WiFiClientSecure client;
  client.setInsecure();
  HTTPClient http;
  if (!http.begin(client, String("https://ntfy.sh/") + NTFY_TOPIC)) return;
  http.addHeader("Title", title);
  int code = http.POST(message);
  logf("[ntfy] POST status: %d", code);
  http.end();
}

void notifyLastReboot() {
  prefs.begin("fanctl", false);
  String reason = prefs.getString("last_reason", "");
  uint32_t count = prefs.getUInt("reboot_count", 0);
  if (reason.length() > 0) {
    prefs.putString("last_reason", ""); // clear so a normal boot stays quiet
  }
  prefs.end();

  if (reason.length() == 0) return;
  if (!NOTIFY_DAILY_REBOOT && reason == REASON_DAILY_REBOOT) return;

  sendNtfy("Fan controller rebooted",
           reason + " (reboot #" + String(count) + ") at " + logTimestamp());
}

RCSwitch myRadio = RCSwitch();

// Fan speed is tracked so onAdjustRangeValue can compute a new absolute value.
int fan1Speed = 0; // 0 = off, 1..3 = low/medium/high
int fan2Speed = 0;

// The physical remote only has a single LIGHT TOGGLE code, not separate
// on/off codes, so we track assumed state locally and only fire the toggle
// when the requested state actually differs from what we last sent. This
// can drift out of sync if the light is ever toggled by another remote.
bool lightState = false;

// Lights the onboard LED for LED_BLINK_MS as visual confirmation an RF
// code was actually sent. Non-blocking: checkLedBlink() (called from
// loop()) turns it back off once the interval elapses, rather than
// stalling command processing/watchdogs with a blocking delay().
bool ledOn = false;
unsigned long ledOnSince = 0;

void ledBlinkStart() {
  digitalWrite(LED_PIN, LED_ON);
  ledOn = true;
  ledOnSince = millis();
}

void checkLedBlink() {
  if (ledOn && millis() - ledOnSince >= LED_BLINK_MS) {
    digitalWrite(LED_PIN, LED_OFF);
    ledOn = false;
  }
}

// Fan 1 and fan 2 can be on different RF families (different frequency,
// rc-switch protocol, and pulse length), so anything transmitting on
// either fan's behalf -- including the light toggles -- must re-tune the
// radio to that fan's family immediately beforehand, rather than assuming
// whatever the radio was last left configured for. Centralized here after
// a real bug: onLightPowerState() sending without re-tuning worked fine
// before fan 2 existed, but silently broke once fan 2's sends could leave
// the radio parked on a different frequency/protocol.
//
// SetTx(mhz), not setMHZ(mhz) -- setMHZ() alone only rewrites the
// frequency registers without re-strobing the chip back into TX state,
// which left the radio stuck out of TX after the first fan2 send (see
// ELECHOUSE_CC1101_SRC_DRV's SetTx(float) implementation: it does
// SIDLE -> setMHZ() -> STX as one atomic sequence).
void tuneRadioForFan1() {
  ELECHOUSE_cc1101.SetTx(FAN1_RF_MHZ);
  myRadio.setProtocol(FAN1_RF_PROTOCOL);
  myRadio.setPulseLength(FAN1_RF_PULSE_US);
}

void tuneRadioForFan2() {
  ELECHOUSE_cc1101.SetTx(FAN2_RF_MHZ);
  myRadio.setProtocol(FAN2_RF_PROTOCOL);
  myRadio.setPulseLength(FAN2_RF_PULSE_US);
}

void sendFan1Code(int speed) {
  tuneRadioForFan1();
#if FAN1_REMOTE_TYPE == REMOTE_TR313A
  switch (speed) {
    case 1: myRadio.send(rfCodeFan1Low, FAN1_RF_BITLENGTH); break;
    case 2: myRadio.send(rfCodeFan1Medium, FAN1_RF_BITLENGTH); break;
    case 3: myRadio.send(rfCodeFan1High, FAN1_RF_BITLENGTH); break;
    default: myRadio.send(rfCodeFan1Off, FAN1_RF_BITLENGTH); break;
  }
#else
  if (speed >= 1 && speed <= FAN1_MAX_SPEED) {
    myRadio.send(rfCodeFan1Speed[speed - 1], FAN1_RF_BITLENGTH);
  } else {
    myRadio.send(rfCodeFan1Off, FAN1_RF_BITLENGTH);
  }
#endif
  ledBlinkStart();
}

void sendFan2Code(int speed) {
  tuneRadioForFan2();
#if FAN2_REMOTE_TYPE == REMOTE_TR313A
  switch (speed) {
    case 1: myRadio.send(rfCodeFan2Low, FAN2_RF_BITLENGTH); break;
    case 2: myRadio.send(rfCodeFan2Medium, FAN2_RF_BITLENGTH); break;
    case 3: myRadio.send(rfCodeFan2High, FAN2_RF_BITLENGTH); break;
    default: myRadio.send(rfCodeFan2Off, FAN2_RF_BITLENGTH); break;
  }
#else
  if (speed >= 1 && speed <= FAN2_MAX_SPEED) {
    myRadio.send(rfCodeFan2Speed[speed - 1], FAN2_RF_BITLENGTH);
  } else {
    myRadio.send(rfCodeFan2Off, FAN2_RF_BITLENGTH);
  }
#endif
  ledBlinkStart();
}

// ==========================================
// SinricPro callbacks
// ==========================================

// "turn on/off the fan" -- the remote has no generic power-on code, so
// powering on defaults to LOW speed.
bool onFan1PowerState(const String &deviceId, bool &state) {
  logf("Fan 1 power: %s", state ? "ON" : "OFF");
  fan1Speed = state ? 1 : 0;
  sendFan1Code(fan1Speed);
  return true;
}

// "set the fan speed" -- range is 1..FAN1_MAX_SPEED
bool onFan1RangeValue(const String &deviceId, int &rangeValue) {
  if (rangeValue < 1) rangeValue = 1;
  if (rangeValue > FAN1_MAX_SPEED) rangeValue = FAN1_MAX_SPEED;
  fan1Speed = rangeValue;
  logf("Fan 1 speed set to %d", fan1Speed);
  sendFan1Code(fan1Speed);
  return true;
}

// relative changes, e.g. "increase the fan speed"
bool onFan1AdjustRangeValue(const String &deviceId, int &rangeValueDelta) {
  fan1Speed = constrain(fan1Speed + rangeValueDelta, 1, FAN1_MAX_SPEED);
  logf("Fan 1 speed adjusted by %d to %d", rangeValueDelta, fan1Speed);
  sendFan1Code(fan1Speed);
  rangeValueDelta = fan1Speed; // must return the new absolute value
  return true;
}

bool onFan2PowerState(const String &deviceId, bool &state) {
  logf("Fan 2 power: %s", state ? "ON" : "OFF");
  fan2Speed = state ? 1 : 0;
  sendFan2Code(fan2Speed);
  return true;
}

bool onFan2RangeValue(const String &deviceId, int &rangeValue) {
  if (rangeValue < 1) rangeValue = 1;
  if (rangeValue > FAN2_MAX_SPEED) rangeValue = FAN2_MAX_SPEED;
  fan2Speed = rangeValue;
  logf("Fan 2 speed set to %d", fan2Speed);
  sendFan2Code(fan2Speed);
  return true;
}

bool onFan2AdjustRangeValue(const String &deviceId, int &rangeValueDelta) {
  fan2Speed = constrain(fan2Speed + rangeValueDelta, 1, FAN2_MAX_SPEED);
  logf("Fan 2 speed adjusted by %d to %d", rangeValueDelta, fan2Speed);
  sendFan2Code(fan2Speed);
  rangeValueDelta = fan2Speed;
  return true;
}

// "turn on/off the light"
bool onLightPowerState(const String &deviceId, bool &state) {
  logf("Light requested: %s (currently tracked as %s)",
       state ? "ON" : "OFF", lightState ? "ON" : "OFF");
  if (state != lightState) {
    tuneRadioForFan1();
    myRadio.send(rfCodeFan1Light, FAN1_RF_BITLENGTH);
    ledBlinkStart();
    lightState = state;
  }
  return true;
}

#ifdef LIGHT2_ID
bool light2State = false;

bool onLight2PowerState(const String &deviceId, bool &state) {
  logf("Light 2 requested: %s (currently tracked as %s)",
       state ? "ON" : "OFF", light2State ? "ON" : "OFF");
  if (state != light2State) {
    tuneRadioForFan2();
    myRadio.send(rfCodeFan2Light, FAN2_RF_BITLENGTH);
    ledBlinkStart();
    light2State = state;
  }
  return true;
}
#endif
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
void loop() {
  SinricPro.handle();
  checkWiFiWatchdog();
  checkSinricWatchdog();
  checkRadioWatchdog();
  checkClockJump();
  checkDailyReboot();
  checkLedBlink();
}

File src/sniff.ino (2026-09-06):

#include <Arduino.h>
#include <ELECHOUSE_CC1101_SRC_DRV.h>
#include <RCSwitch.h>

RCSwitch mySwitch = RCSwitch();

// Pin mappings for ESP32-C3 Super Mini
#define C3_CC1101_CLK   4
#define C3_CC1101_MISO  5
#define C3_CC1101_MOSI  6
#define C3_CC1101_CS    7
#define C3_CC1101_GDO0  3  // Pin connected to GDO0 for capturing pulses

// Frequency to listen on -- change this and reflash to try a different
// candidate frequency (e.g. 315.0 or 304.25) if nothing is received.
#define SNIFF_MHZ 433.92

// 0 = normal mode: only prints when RCSwitch recognizes one of its built-in
// protocols (as below). 1 = raw mode: bypasses RCSwitch's protocol matching
// entirely and just dumps every pulse's duration -- use this when a button
// produces no output in normal mode, to see whether anything is arriving on
// GDO0 at all and, if so, what its actual timing looks like (which can then
// be turned into a custom RCSwitch::Protocol if it doesn't match a built-in
// one).
#define RAW_MODE 0

#if RAW_MODE
#define RAW_MAX_PULSES 500
// A burst is considered finished once this many us pass with no edge --
// long enough to span the gap between repeats within one button press
// (typically a few ms) without also spanning to the *next* button press.
#define RAW_GAP_US 8000

volatile unsigned long rawDurations[RAW_MAX_PULSES];
volatile int rawCount = 0;
volatile unsigned long rawLastEdge = 0;
volatile bool rawHasData = false;

void IRAM_ATTR rawIsr() {
  unsigned long now = micros();
  unsigned long duration = now - rawLastEdge;
  rawLastEdge = now;
  if (rawCount < RAW_MAX_PULSES) {
    rawDurations[rawCount++] = duration;
    rawHasData = true;
  }
}

void dumpRawIfBurstFinished() {
  if (!rawHasData) return;
  if (micros() - rawLastEdge < RAW_GAP_US) return; // still receiving

  noInterrupts();
  int count = rawCount;
  rawCount = 0;
  rawHasData = false;
  interrupts();

  Serial.println("========== RAW BURST ==========");
  Serial.printf("Pulse count: %d\n", count);
  // Skip index 0 -- it's the gap since the *previous* burst, not a real
  // pulse width. Print the rest as a comma-separated list of durations
  // (us), alternating high/low starting from whichever level GDO0 idles
  // low or high at (not tracked here -- eyeball the pattern for repeats).
  for (int i = 1; i < count; i++) {
    Serial.print(rawDurations[i]);
    Serial.print(i + 1 < count ? "," : "\n");
  }
  Serial.println("================================");
}
#endif

void setup() {
    Serial.begin(115200);
    delay(2000);

    Serial.println("--- RF Sniffer Initializing ---");

    // Set custom SPI pins for the C3 Super Mini
    ELECHOUSE_cc1101.setSpiPin(C3_CC1101_CLK, C3_CC1101_MISO, C3_CC1101_MOSI, C3_CC1101_CS);

    // Init() brings up SPI.begin() on the custom pins above, so it must run
    // before any register read (getCC1101 included) or the read fails.
    ELECHOUSE_cc1101.Init();

    if (ELECHOUSE_cc1101.getCC1101()) {
        Serial.println("CC1101 Connection: SUCCESS");
    } else {
        Serial.println("CC1101 Connection: FAILED. Check your wiring!");
        while (1);
    }

    ELECHOUSE_cc1101.setMHZ(SNIFF_MHZ);
    Serial.print("Listening at ");
    Serial.print(SNIFF_MHZ, 2);
    Serial.println(" MHz");
    ELECHOUSE_cc1101.setModulation(2); // Listen for ASK/OOK signals (standard for fan remotes)
    
    // Enable Receiver mode on the chip
    ELECHOUSE_cc1101.SetRx(); 

#if RAW_MODE
    pinMode(C3_CC1101_GDO0, INPUT);
    attachInterrupt(digitalPinToInterrupt(C3_CC1101_GDO0), rawIsr, CHANGE);
    Serial.println("RAW MODE -- dumping pulse timings, no protocol matching.");
#else
    // Connect the data pin to the rc-switch receiver engine
    // On ESP32-C3, you can attach interrupts directly to standard GPIO numbers
    mySwitch.enableReceive(C3_CC1101_GDO0);
#endif

    Serial.println("Ready! Hold your NOMA remote close to the board and press a button.");
}

void loop() {
#if RAW_MODE
    dumpRawIfBurstFinished();
#else
    if (mySwitch.available()) {
        // A valid RF signal protocol was recognized and decoded!
        Serial.println("----------------------------------------");
        Serial.print("Received Code (Decimal): ");
        Serial.println(mySwitch.getReceivedValue());
        
        Serial.print("Bit Length: ");
        Serial.println(mySwitch.getReceivedBitlength());
        
        Serial.print("Protocol Number: ");
        Serial.println(mySwitch.getReceivedProtocol());
        
        Serial.print("Pulse Length (us): ");
        Serial.println(mySwitch.getReceivedDelay());

        // Print raw binary string - use this directly in your transmitter script
        Serial.print("Binary String: ");
        unsigned int len = mySwitch.getReceivedBitlength();
        unsigned long val = mySwitch.getReceivedValue();
        for (int i = len - 1; i >= 0; i--) {
            Serial.print((val >> i) & 1);
        }
        Serial.println("\n----------------------------------------");

        // Clear the receiver buffer to wait for the next button press
        mySwitch.resetAvailable();
    }
#endif
}

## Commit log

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2026-08-10 Add WiFi watchdog and daily scheduled reboot to production firmware
    Guards against the device hanging forever if WiFi is down at boot,
    staying disconnected during operation, or slowly degrading from
    long-running WebSocket/TLS state. Daily reboot is DST-aware via a
    POSIX TZ string rather than a fixed UTC offset.
    Claude-Session: https://claude.ai/code/session_01J3G2VeZfStCP39BGRk4Ehk
    [fan_control.cpp]
2026-08-12 Add radio watchdog, reboot notifications, and fix multi-machine build
    - Add a radio watchdog that periodically re-checks the CC1101 over SPI and
    reboots if it stops responding, since a wedged radio can leave WiFi/
    SinricPro connected (Google still acks) while RF commands silently stop
    sending.
    - Persist each self-triggered reboot's reason to NVS and push it to
    ntfy.sh once WiFi reconnects, so watchdog/reboot activity is visible
    instead of a black box. Manual power cycles stay silent.
    - Add ENABLE_DAILY_REBOOT toggle to make it easy to drop the proactive
    daily reboot later once real watchdog data shows it's unnecessary.
    - Pin the espressif32 platform and Arduino framework versions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
    [fan_control.cpp]
2026-08-12 Log ntfy message content before sending
    The reboot-notification log only showed the HTTP status code, not what was
    actually sent, making it hard to confirm from serial alone which reason/
    count was reported.
    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
    [fan_control.cpp]
2026-08-13 Timestamp all application log output
    Prefix every app-level log line with synced NTP wall-clock time (falling
    back to uptime-in-seconds before NTP has synced), via a new logf() helper,
    so serial output can be correlated with real time instead of just relative
    order -- useful for lining up watchdog reboots with router/network events.
    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
    [fan_control.cpp]
2026-08-13 Fix daily-reboot storm and GMT/EDT timestamp mislabeling
    lastRebootDay only lived in RAM, so any reboot reset it to -1. The first
    checkDailyReboot() call afterward, while still inside the 3am window, saw
    "haven't rebooted today" and immediately rebooted again -- looping for the
    rest of the hour (observed: ~700 reboots in one run). Persist it to NVS so
    it survives the reboot it triggers.
    Also move configTzTime() to the very top of setup(), before any logging.
    The ESP32-C3's RTC survives a soft reset, so time() can already return a
    valid epoch at the start of boot; without the TZ set yet, early log lines
    misread that as UTC/GMT instead of EDT until configTzTime() ran later in
    setupTime(), pro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
    [fan_control.cpp]
2026-08-14 Detect and report resets that bypass our own watchdogs
    A crash, a hung SSL/network stack tripping the hardware watchdog, a
    brownout, etc. reset the chip before any of our own recordRebootReason()
    calls can run -- previously these were completely invisible: no log line,
    no ntfy notification, just an unexplained gap (as seen this morning with
    two reboots that had no recorded cause).
    checkUnexpectedReset() runs first thing in setup() and checks
    esp_reset_reason() against the reset that just happened. If it wasn't a
    normal power cycle/reset button press or one of our own deliberate
    ESP.restart() calls, it's recorded and reported through the same ntfy
    pipeline as every other reboot reason.
    Conf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
    [fan_control.cpp]
2026-08-14 Log background NTP clock jumps
    Diagnosed a confusing log this morning: a WiFi watchdog reboot appeared to
    take ~3 hours to fire, but the raw millis()-based ESP-IDF log lines showed
    it actually happened in ~1 minute as designed. The wall clock itself had
    jumped ~3 hours between two log lines that were only ~14s apart in real
    time -- almost certainly the RTC coming up wrong after the preceding hard
    reset, later corrected by a routine background SNTP re-sync.
    checkClockJump() compares elapsed wall-clock time against elapsed uptime
    every 30s and logs it when they diverge by more than 2 minutes, so a
    correction like this is visible in the log directly instead of requiring
    millis-math to reconstr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
    [fan_control.cpp]
2026-08-15 Speed up SinricPro reconnect detection, add heap diagnostics, fix false-positive reset alerts
    - Enable SinricPro's DEBUG_WIFI_ISSUE build flag, which drops its WebSocket
    ping interval from a 5-minute default to 10s. A half-dead TLS connection
    (socket looks open locally but the peer stopped responding -- the likely
    cause of the recurring ssl_client -76 errors) should now be detected and
    reconnected in ~30s worst case instead of 5+ minutes.
    - Log heap stats (free + largest contiguous block, the latter being what
    actually predicts a fragmentation-caused TLS allocation failure) every
    10 minutes and at every SinricPro disconnect, to test the theory that
    heap fragmentation over multi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
    [fan_control.cpp]
2026-08-16 Remove heap logging, experiment with a 30s SinricPro ping interval
    Heap logging (added to test a fragmentation theory for the recurring
    SinricPro disconnects) showed the largest-free-block staying perfectly
    flat across a 16+ hour window, including right through a disconnect --
    ruling out fragmentation as the cause. No longer needed, removed.
    10s (via DEBUG_WIFI_ISSUE) felt unnecessarily aggressive for a mains-
    powered device with only 2-3 total SinricPro devices. The library only
    exposes a hardcoded 10s/300s toggle with nothing in between and no
    #ifndef guard to override via build_flags, so scripts/patch_sinricpro_ping.py
    patches the installed library's config directly to 30000ms as a Platf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
    [fan_control.cpp]
2026-08-22 Add SinricPro connectivity watchdog
    WiFi.status() staying connected doesn't guarantee SinricPro's WebSocket/
    TLS connection is actually up. Field log showed WiFi stay associated for
    over an hour while SinricPro was unreachable (DNS/TLS failures) -- invisible
    to the WiFi watchdog, which only checks local AP association. It recovered
    only because SinricPro's own internal retry logic eventually got lucky.
    checkSinricWatchdog() polls SinricPro.isConnected() (a live poll straight
    through to the underlying WebSocket client, not a cached flag) and reboots
    if it's been disconnected for 10 minutes, regardless of WiFi state. Reuses
    the existing recordRebootReason()/notifyLastReboot() pipeline, so log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
    [fan_control.cpp]
2026-08-23 Add c3_mini_fan_public target with WiFiManager setup portal
    For sharing with someone else who has the same fan/remote hardware but
    shouldn't need to edit source or a secrets.h to configure their own WiFi/
    SinricPro credentials.
    - New environment c3_mini_fan_public / src/fan_control_public/, built from
    c3_mini_fan: same CC1101 wiring, RF codes, and reliability watchdogs
    (WiFi, SinricPro, radio, daily reboot, unexpected-reset detection, clock-
    jump logging), but no secrets.h.
    - WiFiManager (tzapu/WiFiManager) captive portal collects WiFi credentials
    plus four custom fields (SinricPro App Key/Secret, Fan/Light device IDs)
    at first boot, persisted to NVS (separate "fanwm" namespace) a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
    [fan_control_public.cpp]
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2026-08-25 Add hostname/mDNS, ArduinoOTA, and button-hold factory reset to public build
    Scoped entirely to c3_mini_fan_public (src/fan_control_public/), not the
    personal c3_mini_fan build:
    - Device hostname (default "myfan", overridable in the WiFiManager portal
    alongside the SinricPro fields) via WiFi.setHostname(), reachable at
    <hostname>.local via ESPmDNS once connected. Persisted in the same
    "fanwm" NVS namespace as the other portal-collected config.
    - ArduinoOTA for flashing over WiFi during development (pio run -t upload
    --upload-port <hostname>.local), discoverable via the same mDNS hostname.
    - Holding the BOOT button (GPIO9 on most ESP32-C3 boards) for 10s wipes the
    "fanwm" NVS names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
    [fan_control_public.cpp]
2026-08-25 Make public build tolerant of a missing CC1101 module
    Diagnosed why a bare ESP32-C3 test unit (no CC1101 attached) never showed
    the WiFiManager setup portal: setupRadio() runs before setupWiFiManager()
    in setup(), and it's plausible CC1101 init/config calls on a chip that
    isn't physically present could hang or otherwise prevent ever reaching the
    WiFi/portal logic.
    Track whether the CC1101 actually responded (radioAvailable, set once in
    setupRadio() from getCC1101()'s result) and skip the rest of CC1101-specific
    setup/sends/watchdog when it's false, so WiFi/SinricPro/portal/OTA/reset-
    button testing can proceed on hardware without the radio attached:
    - setupRadio() returns early after loggin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
    [fan_control_public.cpp]
2026-08-25 Force clean WiFi radio reset before opening the setup portal
    Field-observed: on the first setup attempt, a phone joining the SoftAP
    right as it started got a 169.254.x.x self-assigned link-local address
    instead of a real DHCP lease from the ESP32 -- meaning it couldn't reach
    192.168.4.1 at all (different subnet, no route), not just a captive-portal
    auto-popup failure. A second reconnect attempt (after some delay) worked.
    Added WiFi.mode(WIFI_OFF) + a 200ms delay right before autoConnect(), a
    commonly-reported mitigation for this exact WiFiManager symptom: without
    it, the SoftAP/DHCP server transitioning from a failed/nonexistent STA
    attempt into AP mode can be mid-startup when a device trie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
    [fan_control_public.cpp]
2026-08-25 Add boot banner and firmware version to both builds
    FIRMWARE_VERSION (format YYYY-MM-DDrN, bumped manually on each flash worth
    tracking) now prints in the boot log line, e.g. to confirm an OTA update
    on the public build actually took effect. Also added an ASCII art banner
    at the very top of boot output, printed via a raw string literal (C++11
    R"(...)") to avoid having to escape the backslashes in the art itself.
    Applied to both fan_control.cpp and fan_control_public.cpp for parity, each
    with its own independently-bumped version constant since the two builds
    get updated on different schedules.
    Verified on hardware: banner and version render correctly on the
    production unit, boot proceeds no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
    [fan_control.cpp, fan_control_public.cpp]
2026-08-25 Fix banner alignment, bump to r2
    First row of the ASCII banner needed one more leading space to align with
    the rest of the glyphs.
    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
    [fan_control.cpp, fan_control_public.cpp]
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2026-08-25 Fix factory reset not actually erasing saved WiFi credentials
    Field report: after the reset button fired, the "fanwm" NVS namespace was
    confirmed cleared (NOT_FOUND for all fields on next boot) but WiFiManager
    still found and reconnected using a saved AP ("AirNet") instead of opening
    the setup portal -- the WiFi credential erase silently didn't take effect.
    WiFiManager's own resetSettings() calls WiFi_enableSTA(true, true) and
    waits 500ms before disconnect(true, true), specifically because STA mode
    must be active for the erase to actually happen ("must be sta to
    disconnect erase", per its source comment). Our implementation skipped
    that prerequisite when I bypassed needing a persistent WiFi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
    [fan_control_public.cpp]
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2026-08-26 Fix button hole placement, add ventilation grid to case lid
    - Button is top-mounted (pressed straight down), not on a side edge --
    moved the poke-hole tunnel from the bottom shell's front wall to a
    vertical hole through the lid, and bumped its diameter 2.5->3mm so it
    reads as visually/physically distinct from the vent dot grid.
    - Added a ventilation dot grid across the lid top (2mm holes, 6mm pitch),
    automatically skipping any dot within 6mm of the LED or button holes so
    nothing merges together.
    Verified: re-rendered, both holes land correctly with clear clearance
    halos in the vent pattern; both STL exports remain manifold ("Simple: yes").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
    [fan_dongle_case.scad]
2026-08-26 Move reset button hole to the left side facing the USB port
    button_hole_y: 4 -> 20 (mirrored to the opposite long edge), per field
    correction on the real module's button placement.
    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
    [fan_dongle_case.scad]
2026-08-26 Fix lid skirt being a solid slab instead of a hollow ring
    The skirt (the friction-fit lip that inserts into the bottom shell) was
    a plain filled cube spanning the entire cavity footprint, which showed
    up as an unwanted solid floor under the lid's component cavity. Now
    it's a proper thin ring via a nested difference().
    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
    [fan_dongle_case.scad]
2026-08-26 Fix lid outer wall overlapping the friction-fit skirt
    The lid's full-height outer wall (matching the bottom shell's outer
    footprint) started at Z=0, the same height range as the separate,
    narrower friction-fit skirt -- producing two concentric wall rings
    with a small gap between them instead of one wall. Now the outer wall
    starts above the skirt (Z=lip_h) so the lid sits flush on top of the
    bottom shell's rim, with only the skirt stepping down into its cavity.
    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
    [fan_dongle_case.scad]
2026-08-27 Rework case as pin/hook slide-in assembly, no screws
    Replaces the screw-together clamshell with a no-screw, slide-in design:
    - bottom_tray(): open-ended U-channel (floor + 2 long walls + 1 closed
    far-end wall). The near end is open, doubling as the cable exit and
    the entry point for the top piece. Mounting pads now carry plain
    alignment pins instead of self-tap screw pilot holes -- the PCB is
    located by its own mounting holes sliding over these pins, not
    screwed down.
    - top_slide(): ceiling + 2 skirt walls that nest just inside the
    tray's own walls (not over the outside) and slide in lengthwise
    from the open end until the tray's far wall stops it. A keyhole-
    slotted hook ta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
    [fan_dongle_case.scad]
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2026-08-27 Tighten skirt groove so it doesn't cut through the wall
    The groove cut for the rail interlock was padded an extra 1.5mm beyond
    what the rail actually needs, on the theory that oversized was safer.
    In practice that left only 0.7mm of skirt material behind the groove
    on one side, and on the other side removed the skirt's full 2mm
    thickness entirely (a mirroring mistake compounded the padding).
    Resized both grooves to just rail_protrusion + rail_clearance deep, so
    the 2mm skirt wall keeps a consistent ~1.2mm of solid backing material
    behind the groove.
    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
    [fan_dongle_case.scad]
2026-08-27 Add reset-button guide tube, drop the external LED hole
    Reset button: the poke-hole was just a straight bore through the
    ceiling with nothing below to aim it. Added a tube (button_tube_od,
    wall thickness button_tube_wall) hanging from the ceiling down toward
    the board, stopping button_tube_gap_above_board above it, with the
    same bore continuing all the way through -- guides a toothpick/pin
    straight to the button instead of relying on a thin 2mm hole.
    LED: dropped the dedicated external LED hole. The onboard LED
    (GPIO8/GND) will show through the ceiling's vent holes instead, so no
    separate hole or panel-mount LED is needed. vent_holes() no longer
    excludes the old LED position, only the butto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
    [fan_dongle_case.scad]
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2026-08-27 Shrink cable slot to cable width, add tray-side stub wall
    Cable slot: reduced usb_hole_d from 6mm to 4mm -- it should only need
    to fit the cable's own diameter, not a connector, since the slot is
    already open at the bottom for plugging in first.
    Near-end stub wall: the tray's open (cable) end previously had zero
    wall of its own, relying entirely on the top piece's leading wall for
    closure. Added a fixed stub wall on the tray covering the bottom third
    (end_wall_frac) of that opening. Since the top slides in horizontally,
    it can't pass through space the tray's stub wall already occupies, so
    the top's leading wall was correspondingly shortened to start exactly
    where the stub wall stops (end_wa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
    [fan_dongle_case.scad]
2026-08-27 Add DIP-switch RF code lookup table for multi-fan support
    Sniffing the same 5 buttons across 3 different remote DIP switch
    combinations showed the 12-bit code splits cleanly: the upper 8 bits
    are the button, unaffected by the switches, and the low 4 bits are
    exactly the DIP address (switch 1 = bit 3 down to switch 4 = bit 0,
    OFF=1/ON=0). Both firmwares now store a "base" code per button
    (address nibble 0000, all switches ON) and compute the real codes at
    boot as base | address_nibble, instead of 5 fixed codes baked in for
    one specific switch setting.
    c3_mini_fan (secrets.h): DIP_SWITCH_1..4 booleans, matching this fan's
    actual remote (1=off, 2=off, 3=on, 4=on).
    c3_mini_fan_public: 4 new Wi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
    [fan_control.cpp, fan_control_public.cpp]
2026-08-27 Move button back to the right side, add top bevel
    Button: flipped button_hole_y from 20 back to 4 (mirrored around the
    board's Y center) -- the "left when facing the port" read on the real
    hardware turned out backwards; it's actually on the right.
    Bevel: added a cosmetic 45-degree bevel around the top face's outer
    edge (all 4 sides) via a new beveled_top() module -- a hull() between
    the full-size box up to (wall_t - top_bevel) and an inset box at the
    top, tapering the last top_bevel of height/width.
    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
    [fan_dongle_case.scad]
2026-08-27 Add matching tray bevel, locking screw, and PCB fit-check reference
    Bevel: the tray's two long side walls now get the same 45-degree
    cosmetic bevel as the top's outer edge, applied only to the
    exterior-facing surface (beveled_wall_low/high) so it doesn't disturb
    the rail or the skirt fit on the interior side.
    Locking screw: the rail/groove stops the top lifting straight off, but
    nothing stopped it sliding back open. Added an M3 locking screw
    straight down through the tray floor (recessed counterbore on the
    underside) into a blind self-tap boss hanging from the top's ceiling,
    positioned past the closed far end of the board. Needed stretching the
    case by far_end_extra (10mm) past the board's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
    [fan_dongle_case.scad]
2026-08-27 Rework assembly as vertical drop, screw is the actual lock
    Working through the mechanics (prompted by a good question about what
    actually stops the top lifting off) surfaced two real problems with
    the horizontal-slide-in design from the last several commits:
    1. Hooks/button tube/screw boss all hang within a couple mm of the
    board. A full-length horizontal slide-in drags all of them across
    the board's entire surface to reach their final position, not just
    settles them there -- they'd hit the ESP32/CC1101 modules and any
    other components along the way.
    2. A short "drop then lock-slide" fix (the initially proposed remedy)
    doesn't actually work either: the hook's hole has to be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
    [fan_dongle_case.scad]
2026-08-27 Fix short-side bevel, center vent grid, replace screw with snap-fit
    Bevel: the leading (near/cable-end) wall extended all the way up
    through the ceiling's own bevel zone (to ceiling_top_z), filling the
    taper back in flat. Stops at ceiling_bot_z instead, so the ceiling's
    45-degree edge shows through on that short side same as the other 3.
    Vent grid: was anchored at vent_margin and stepped by vent_spacing
    until it ran out of room, leaving an arbitrary leftover gap on one
    side. Now computes how many rows/columns actually fit and centers the
    grid on the ceiling, with equal margin on every side. Also dropped
    vent_margin 8->6mm, which fits a 4th row instead of 3.
    Screw -> snap-fit: the locking s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
    [fan_dongle_case.scad]
2026-08-27 Replace dot-grid vents with a parametric wave/ripple texture
    Adds wave_texture(): shallow cosmetic grooves (0.6mm, wave_amplitude)
    run across the ceiling's full width, repeating along its length at
    wave_spacing, centered with equal margin on both ends. Each groove
    gets a narrow through-slot (vent_slot()) cut at its lowest point for
    actual airflow, split into two segments around the button tunnel when
    a groove lands close to it, instead of the old round dot grid.
    This is a regular, repeating parametric approximation of an organic
    flow-field surface (like a reference photo the user shared), not a
    mesh-sculpted match to one -- OpenSCAD's CSG modeling doesn't
    naturally produce true freeform org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
    [fan_dongle_case.scad]
2026-08-27 Recessed USB-C port (guessed), rounded fillets replace the bevel
    USB-C port: replaces the old open-bottom cable slot entirely. Assumes
    the Super Mini's own onboard USB-C connector sits right at this
    opening rather than a soldered/attached cable -- nothing threads
    through during assembly, you just plug in from outside once the case
    is closed. A shallow surface recess (usb_port_recess_margin/depth)
    surrounds a smaller through-opening for the stepped-in receptacle
    look. Every usb_port_* dimension is a guess, explicitly flagged --
    none of it is measured off the real connector yet.
    Rounded fillets: replaces the 45-degree chamfer (beveled_top/
    beveled_wall_low/high) with a true curved fillet (rou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
    [fan_dongle_case.scad]
2026-08-27 Add a 2nd snap point per wall, extend rounding to more edges
    Snap-fit: was one centered tab per long wall -- nothing was actually
    catching the ceiling near the ends, which could still flex/lift there
    even with the middle snapped shut (caught by the user looking at the
    render, not something I'd verified). Now two tabs per long wall,
    spread toward each end (20%/80% along the board's length) instead of
    one in the middle. snap_x is now snap_x_list, and both the ridge
    placement (bottom_tray) and tab relief cuts (top_slide) loop over it.
    Rounding: extended the same rounded-fillet treatment from the last
    commit (ceiling top edge + 2 long walls) to the tray's far end wall
    (rounded_wall_x_high(), a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
    [fan_dongle_case.scad]
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2026-08-30 Fix WiFi connect reliability and NTP timing on ESP32-C3 boards
    Caps TX power to 15dBm before connecting (esp_wifi_set_max_tx_power) --
    confirmed fix for an ESP32-C3 SuperMini issue where full TX power
    (~19.5dBm peak) browns out the onboard regulator during transmit
    bursts, causing a board that would only connect to WiFi if you
    physically touched the antenna. Also grounds the floating GPIO21 pin
    near the antenna as a harmless precaution (tried alone first, didn't
    fix the issue by itself).
    Also fixes NTP sync failing on first boot: configTzTime() (which also
    starts the SNTP client) was being called before WiFi connects, wasting
    the client's first sync attempt with no network up yet -- re-kick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
    [fan_control.cpp, fan_control_public.cpp]
2026-08-30 Update case design: real component dimensions, USB port, extra clip
    hw/case/fan_dongle_case.scad:
    - ESP32-C3 SuperMini footprint corrected to its real published size
    (22.5 x 18mm) -- was backwards and oversized on one axis.
    - CC1101 module footprint/position corrected using a detailed reference
    model of the real board (it's much bigger than the socket footprint
    alone) -- fixes case length, hook-post clearance, and a half-cap
    direction bug that had material pointing straight into the module.
    - USB port opening resized to fit an actual cable plug (not just the
    bare connector), and repositioned: top edge flush with ceiling_bot_z
    so it doesn't visually cut into the ceiling seam, clos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
    [bottom-final.stl, bottom-final2.stl, fan_dongle_case.scad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]
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
